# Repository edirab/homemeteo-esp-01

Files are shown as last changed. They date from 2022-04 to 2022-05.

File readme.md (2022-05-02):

## Проект домашней метеостанции на ESP-01 и Arduino

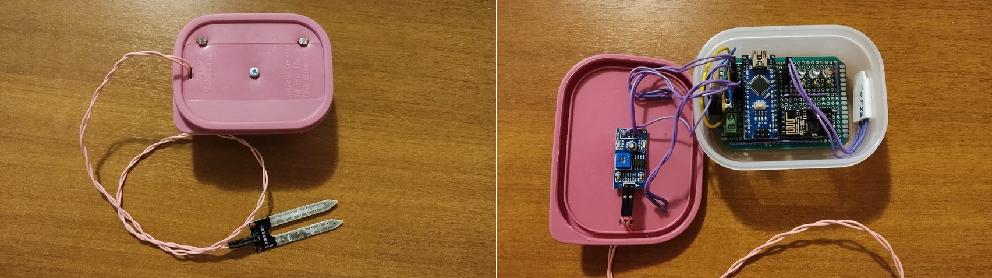
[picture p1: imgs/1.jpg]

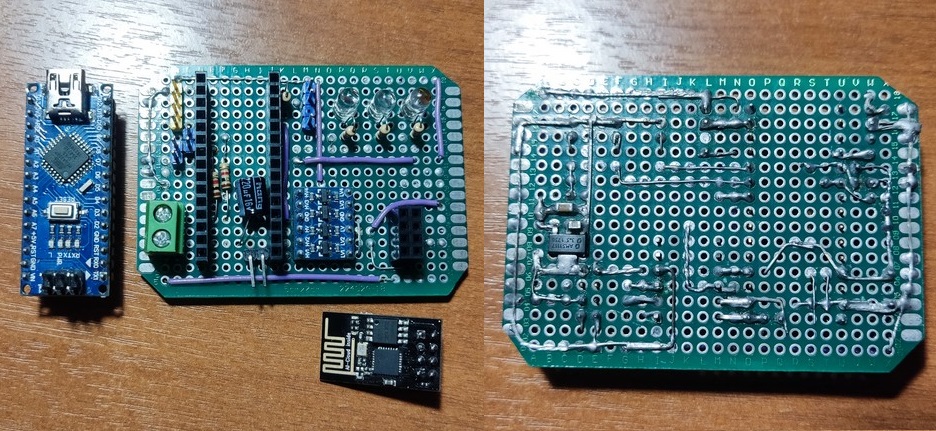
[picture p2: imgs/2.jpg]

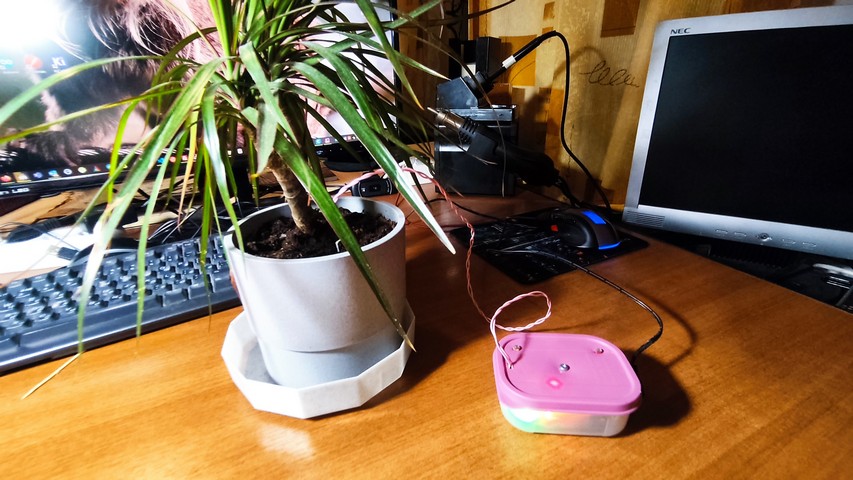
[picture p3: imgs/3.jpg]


### О проекте:

Устройство раз в 2 секунды собирает данные о 
- температуре, 
- влажности воздуха, 
- влажности почвы и 
- относительной освещённости в двух точках 

Пакет по локальной сети через wifi отправляется MQTT-брокеру `mosquitto`, развёрнутом на `Raspberry Pi 3B`. Скрипт `mqtt_test.py`, который обработывает callback от брокера, накапливает данные, добавляет к ним временную метку и раз в 10 минут производит запись в базу данных.

Раз в сутки производится резервное копирование БД на флешку.
За день накапливается ~1,7 Mb

Собранные данные можно проанализировать и определить, например, 
- частоту полива цветка
- изменения температуры и влажности воздуха с временами года,
- изменение освещённости в течение дня и в течение года
- оценить продолжительность светового дня
( в том числе и во сколько автор ложится спать :) )

### Цели проекта: 

- освоить микроконтроллер `ESP 8266` в его проестейшей версии `ESP 01`
- познакомиться с протоколом MQTT
- реализовать надёжную двунаправленную связь по UART между микроконтроллерами на основе протокола с подтверждением
- углубить познания в отладке `cron`

### Состав репозитория

- Скетч `meteo.ino` для Arduino
- Скетч `esp_test.ino` для ESP-01
- Python-скрипт `mqtt_test.py`
- `bash`-скрипт для резервного копирования
- Проект KiCad 6.0: 
    + схема электическая принципиальная
    + примерная компоновка печатной платы
    + Bill of materials
- фото устройства
- описание для настройки автозапуска

### Развёртывание ПО

1. Установить зависимости
```shell
sudo apt update && sudo apt upgrade
pip3 install pysqlite3
pip3 install paho-mqtt
pip3 install python-telegram-bot --upgrade
pip3 install matplotlib
sudo apt install -y mosquitto mosquitto-clients
sudo systemctl enable mosquitto.service
```
2. Настроить `mqtt`-брокер
- отредактировать системный конфигурационный файл или
```shell
sudo nano /etc/mosquitto/mosquitto.conf
> listener 1883
> allow_anonymous true
```
- скопировать конфигурацию `my.conf`: `sudo cp <path_to_repo/my.conf> /etc/mosquitto/conf.d/`

3. `sudo reboot`
4. Проверка конфигурации брокера:
```shell
	mosquitto_sub -d -t hello/world
	mosquitto_pub -d -t hello/world -m "Hello from Terminal window 2!"
	mosquitto_sub -t home/#
```

### Настройка автозапуска приложения и резервного копирования

1. Устанавливаем права и запускаем вручную, чтобы создать первоначальный файл базы данных на флешке.
```shell
chmod +x *.sh
./mqtt_backup.sh
```
2. Редактируем таблицу `cron` от имени обычного пользователя. Явно добавляем переменные окружения, т.к. у `cron` они отличаются
```shell
crontab -e

SHELL=/bin/bash
HOME=/home/pi
PATH=/usr/local/sbin:/usr/local/bin:/usr/sbin:/usr/bin:/sbin:/bin:/usr/local/games:/usr/games	

@reboot 	 /usr/bin/python3 /home/pi/Documents/mqtt_test.py >> /home/pi/Documents/1.log &
# Каждый день в 15:50
50 15 * * *  /bin/bash  /home/pi/Documents/mqtt_backup.sh
```

3. Считываем заново таблицу
```shell
sudo service cron reload
```
4. Проверка автозапуска
```shell
sudo reboot
ps -ax | grep mqtt
```

#### Важно при настройке автозапуска по cron

1. Пути ко всем ресурсам как в `crontab`, так и внутри скрипта, лучше прописывать абсолютные
2. Ресурсы, к которым обраются скрипты, должны иметь соотв. права (БД и файл логов доступны для чтения/записи)
3. Использовать лучше таблицу для обычного пользователя, а не `root`, в противном случае придётся устанавливать все библиотеки и для root: `sudo pip3 install pysqlite3`
4. ! Формат записи: `# m h  dom mon dow   command` - сначала минуты!
5. Про переносе файла с windows на linux могут слететь окончания строк: `dos2unix <file>`
6. Для отладки пользоваться гайдом [отсюда](https://stackoverflow.com/questions/22743548/cronjob-not-running)

### Процесс разработки

- [x] Устанока и настройка `mqtt`-брокера на Raspberry Pi
- [x] Поиск/проверка скрипта на python для записи данных, полученных от брокера
- [x] Разработка тестового ПО для ESP-01 для отладки приёма данных по MQTT. Например, посылка миллисекунд с момента включения
- [x] Определиться что будем использовать: ардуино в связке в esp 01

- [x] Для этого нужно определиться с составом датчиков. Берём
  + DHT 22 (влажность/температура)
  + Влажность почвы (аналоговый вход)
  + Пара фоторезисторов (аналоговые входы)
	
- [x] Разработать формат UART-посылки. Принят такой вариант:
	`27.2 35.6 3 456 645\r\n`

- [x] Разработать метод для разбора посылки на стороне esp 01, пришедшей по последовательному интерфейсу
- [x] Протестировать взаимодействие устройств на макетной плате -> Минимальное жизнеспособное приложение!
- [x] Добавить 3 светодиода на ардуино: 
  + красный для сигнализации о потере mqtt-соединения,
  + жёлтый - сухая почва цветка
  + зелёный для сигнализации о потере wifi-соединения,

- [x] Начертить схему электрическую принципиальную
- [x] Сделать компоновку печатной платы
- [x] Собрать устройство на паечной макетной плате

- [x] Необходимо разработать более надёжный протокол управления, основанный на сообщениях 
с уникальными префиксами и подтверждениями 

- [x] Доработать скрипт на python. Нельзя вести запись на карту памяти каждые 2 секунды.
	Слишком большой износ. Сделать раз в 3-5 минут
- [x] Изменить схему базы данных для более компактного хранения данных

- [ ] Добавить обработку ЖЁЛТОГО светодиода, подобрать пороговое значение для влажности почвы
- [ ] Оформить проект красиво: сделать фото устройства, составить Bill of Materials, сохранить в pdf схему эл. принц.

- [x] Разобраться как настроить автозапуск скрипта при старте Raspbian

- [x] Добавить `bash`-скрипт для резервного копирования БД на флешку раз в сутки по `cron`
- [ ] Сделать бота для Телеграм, чтобы можно было получить доступ к данным из любой точки мира с телефона. Продумать функционал

- [ ] Как насчёт добавить какой-либо пользовательский интерфейс для задания новых
  + логина/пароля для wifi-сети,
  + ip-адреса mqtt-брокера

### Заметки

- [Задать пароль и пользователя для брокера mosquitto](http://www.steves-internet-guide.com/mqtt-username-password-example/)

- Откуда взят [mqtt_test.py](https://lindevs.com/save-mqtt-data-to-sqlite-database-using-python/)

### Настройка VS Code для работы с Arduino

- Установить плагин Arduino
- Прописать путь к библиотекам, устанавливаемым через менеджер: 
	`corsair2\\Documents\\Arduino\\libraries` в `arduino.json`
- Добавить параметр `"output": "build"` в `arduino.json`

- Логин пароль `esp/esp`

### Bootloader debug messages

При загрузке esp выкидывает в uart отладочную информацию о работе загрузчика.
Поделать с этим ничего нельзя, только проигнорировать.
Скорость baudrate 74800 bit/s

Для отключения подобного вывода необходимо GPIO 15 (MTDO) [притянуть к нулю](https://www.esp32.com/viewtopic.php?t=10597) ,
но на ESP-01 вывод не разведён

```
	Posting for someone who still needs help on this topic.
	[Note: I'm using IDFv4.4 dev]

	Step1: got to menuconfig -> component config -> esp system settings -> channel for console output
	Set to - Custom UART
	Come one level behind and you'll find new options: UART peripheral to use for console output
	Set this to UART1
	You may also change the pins for UART0/1 that you are using now, by writing them in "UART Tx in GPIO# " option,
	if you want to use UART0 pins (Tx-GPIO1 & Rx-GPIO3) for other purposes or simply change their respective pins to somewhere more convenient while designing a complex PCB.

	Now, save and quit menuconfig -> flash operation is always done through UART0 (GPIO 1&3) but monitoring can now be done through UART1
	However, on every reset (POWER_ON/SW_RESET/WDT_RESET, etc.) the UART0 pins will output bootloader logs even-though they are supposed to be printed through UART1. For this, I tried setting BOOTLOADER and LOGOUTPUT to NONE in menuconfig, but it only stopped printing the respective logs on UART1 (coz. we had set it that way).

	The real solution is to pulldown GPIO15 so that even those bootup logs at UART0 can be stopped and now you're free to use the GPIO 1&3 for I/O operations.
```

Единственный вариант - пропустить эти сообщения

### Отладка автозапуска

Способы настройки автозапуска
- rc.local
- init.d
- systemd
- cron
- .bashrc

##### 1. Скрипт dbg_cron.py

1.1 Для отладки запуска в cron по reboot создадим простой скрипт.
Просто выводим дату и время в файл

В crontab обычного пользователя добавим 
	@reboot /usr/bin/python3 /home/pi/Documents/dbg_cron.py

- Просмотр изменений файла:
	watch -n 1 tail -1 /tmp/dbg_cron.log
	sudo tail -n20 -f /var/log/mosquitto/mosquitto.log
	sudo cp /home/pi/Documents/mymqttclient.service /etc/systemd/system/

=====

cat /var/log/syslog | grep cron
cat /var/log/syslog | grep CRON
tail -f /var/log/syslog

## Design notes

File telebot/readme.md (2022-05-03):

### Configuring bot

Список команд
start - запустить бота
help - вывести список команд
recent - получить последние данные
daily - статистика за сегодня

### Запуск бота в фоне и отвязка от консоли

```shell
	./bot.py &> /dev/null &
	disown <process-pid>
```

### TODO

- Выполнение команды /daily на RPI 3 занимает около 40 секунд, что слишком много.
Необходимо уменьшить выборку, скажем, до 300 точек

- Зафиксировать размер подмножества для одного графика. Скажем, 100 точек
- Сделать нормальные временные метки. Каждый час или каждые полчаса.
Зависит от диапазона измерений

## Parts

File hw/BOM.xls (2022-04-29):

Source: | D:\PycharmProjects\arduino\esp-mosquitto\hw\esm_mosquitto\esm_mosquitto.kicad_sch
Date: | 30.04.2022 0:29:25
Tool: | Eeschema (6.0.4)
Generator: | C:\Program Files\KiCad\6.0\bin\scripting\plugins/bom_csv_grouped_by_value_with_fp.py
Component Count: | 21
Ref | Qnty | Description
A1 | 1 | Arduino_Nano v3
C1 | 1 | Capacitor D5_P2.5 mm 220 u
C3 | 1 | Capacitor SMD 0805 10u
C4 | 1 | Capacitor SMD 0805 22u
D1 | 1 | LED D5 mm Green
D2 | 1 | LED D5 mm Yellow
D3 | 1 | LED D5 mm Red
J1 | 1 | Pin Header 2.54 mm 1x04 Vertical
J2 | 1 | Barrel_Jack P5 mm
R1, R3 | 2 | GL55 Photoresistor
R2, R4 | 2 | Resistor_L6.3mm_D2.5mm 1k
R5 | 1 | Resistor_L6.3mm_D2.5mm 10k
R8 - R10 | 3 | Resistor_L6.3mm_D2.5mm 470 Ohm
U1 | 1 | ESP-01 module
U2 | 1 | DHT 11 - Temperature and humidity module
U3 | 1 | Logic_Level_Converter BSS138
U5 | 1 | AMS1117-3.3 SOT-223 - 1A Low Dropout regulator

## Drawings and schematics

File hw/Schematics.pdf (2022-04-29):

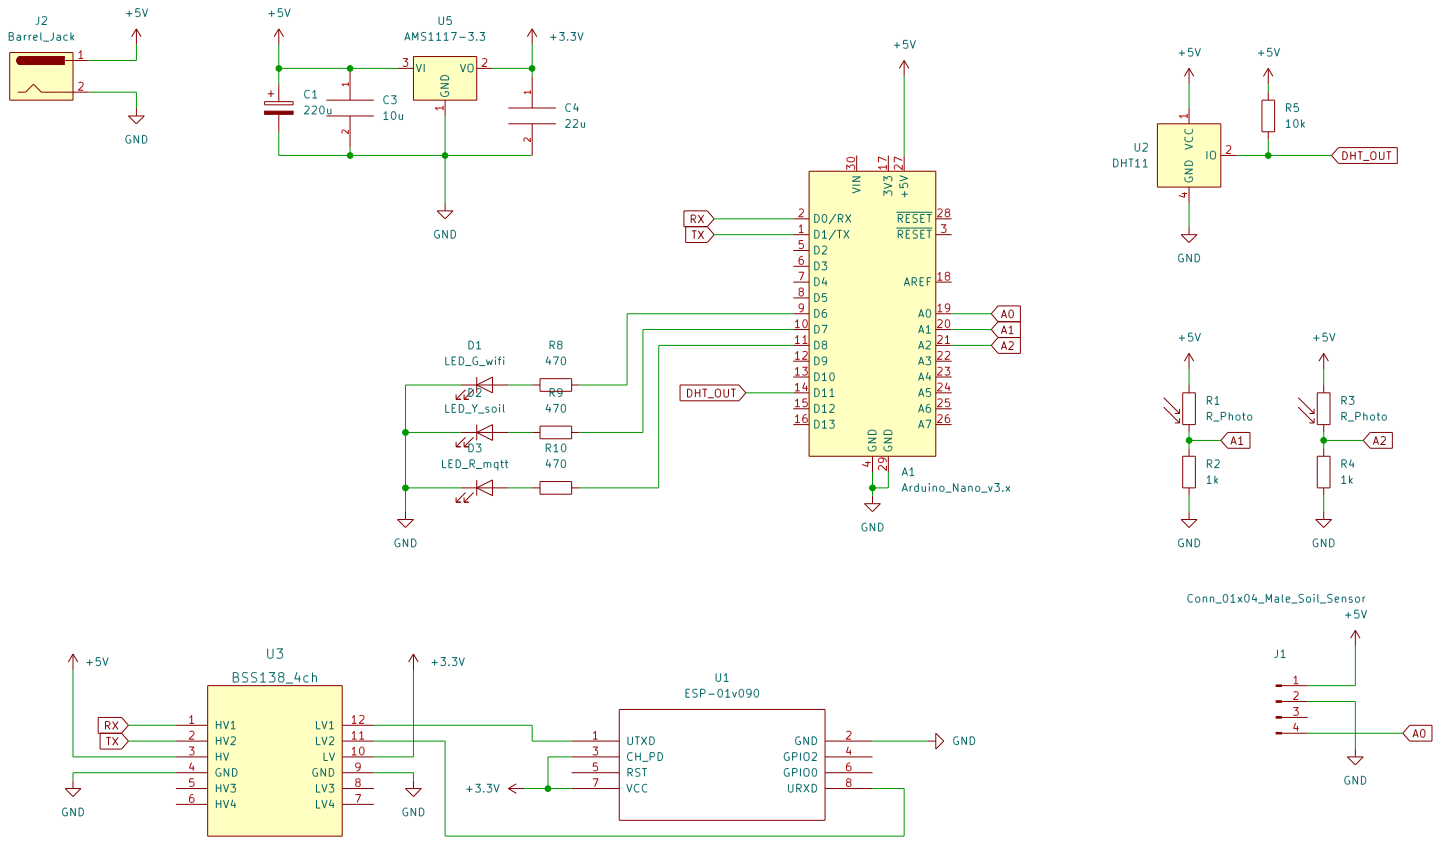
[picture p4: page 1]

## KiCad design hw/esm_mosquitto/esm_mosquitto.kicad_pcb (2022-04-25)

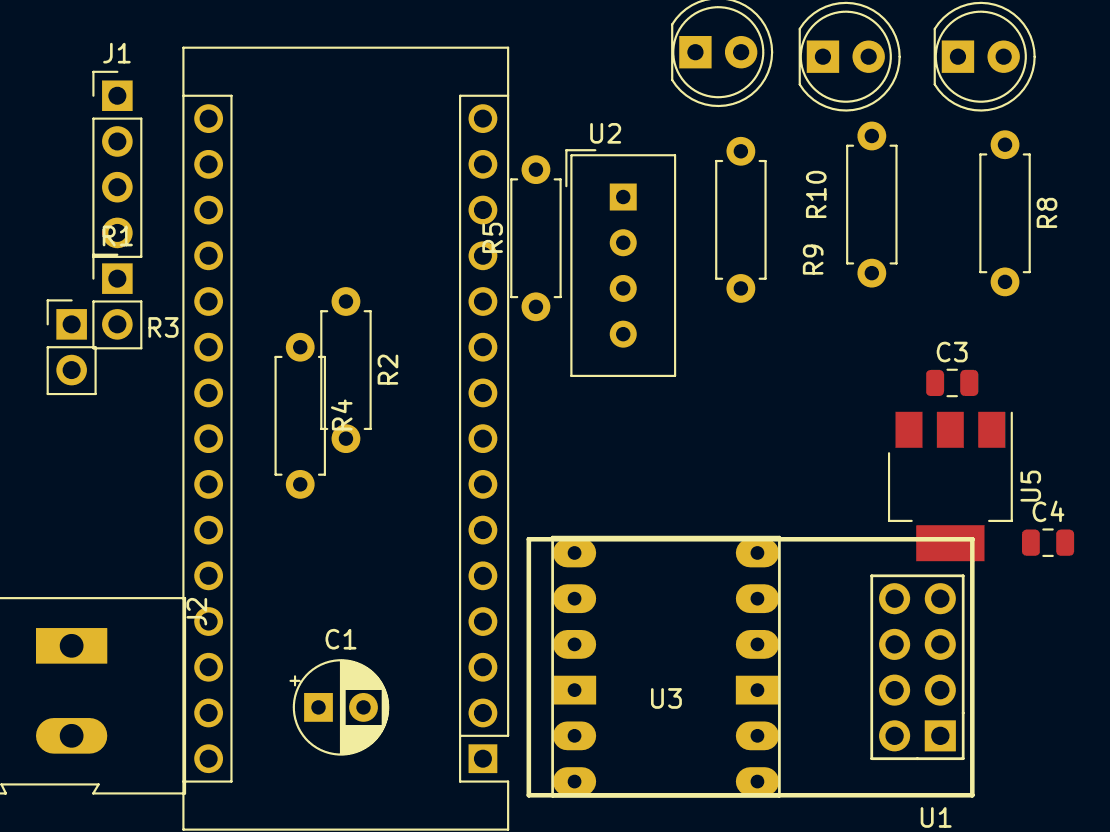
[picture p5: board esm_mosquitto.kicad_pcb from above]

Board: 2 copper layers, 21 parts (0 on the bottom side), 17 nets, no tracks yet.

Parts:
A1: Arduino_Nano_v3.x; Arduino_Nano
C1: 220u; CP_Radial_D5.0mm_P2.50mm
C3: 10u; C_0805_2012Metric
C4: 22u; C_0805_2012Metric
D1: LED_G_wifi; LED_D5.0mm_Clear
D2: LED_Y_soil; LED_D5.0mm_Clear
D3: LED_R_mqtt; LED_D5.0mm_Clear
J1: Conn_01x04_Male_Soil_Sensor; PinHeader_1x04_P2.54mm_Vertical
J2: Barrel_Jack; TerminalBlock_Altech_AK300-2_P5.00mm
R1, R3: R_Photo; PinHeader_1x02_P2.54mm_Vertical
R2, R4: 1k; R_Axial_DIN0207_L6.3mm_D2.5mm_P7.62mm_Horizontal
R5: 10k; R_Axial_DIN0207_L6.3mm_D2.5mm_P7.62mm_Horizontal
R8, R9, R10: 470; R_Axial_DIN0207_L6.3mm_D2.5mm_P7.62mm_Horizontal
U1: ESP-01v090; ESP-01
U2: DHT11; Aosong_DHT11_5.5x12.0_P2.54mm
U3: BSS138_4ch; BSS138
U5: AMS1117-3.3; SOT-223-3_TabPin2

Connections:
+3V3: C4.1, U1.3 (CH_PD), U1.7 (VCC), U3.10 (LV), U5.2 (VO)
+5V: A1.27 (+5V), C1.1, C3.1, J1.1, J2.1, R1.1, R3.1, R5.1, U2.1 (VCC), U3.3 (HV), U5.3 (VI)
A0: A1.19 (A0), J1.4
A1: A1.20 (A1), R1.2, R2.1
A2: A1.21 (A2), R3.2, R4.1
DHT_OUT: A1.14 (D11), R5.2, U2.2 (IO)
GND: A1.4 (GND), A1.29 (GND), C1.2, C3.2, C4.2, D1.1 (K), D2.1 (K), D3.1 (K), J1.2, J2.2, R2.2, R4.2, U1.2 (GND), U2.4 (GND), U3.4 (GND), U3.9 (GND), U5.1 (GND)
unnamed: A1.9 (D6), R8.2
unnamed: A1.10 (D7), R9.2
unnamed: A1.11 (D8), R10.2
unnamed: D1.2 (A), R8.1
unnamed: D2.2 (A), R9.1
unnamed: D3.2 (A), R10.1
unnamed: U1.1 (UTXD), U3.12 (LV1)
unnamed: U1.8 (URXD), U3.11 (LV2)
RX: A1.2 (D0/RX), U3.1 (HV1)
TX: A1.1 (D1/TX), U3.2 (HV2)

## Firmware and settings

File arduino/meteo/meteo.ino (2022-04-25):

#include <DHT_U.h>
#include <DHT.h>

 
#define DHTPIN  11     // what pin we're connected to
#define DHTTYPE DHT22   // DHT 22  (AM2302)

#define LED_MQTT 8 //  Red
#define LED_SOIL 7 // Yellow
#define LED_WIFI 6 // Green


#define DEBUG_PIN 5

// conn statuses
#define MSG_PREFIX "METEO_"
#define WIFI_FAIL 1
#define WIFI_OK	2
#define MQTT_FAIL 3
#define MQTT_OK 4


#define PERIOD 2000 // msec

struct luminance
{
    uint16_t r1;
    uint16_t r2;
};

struct meteo_data
{
    String temp, hum, soil;
    String lum1, lum2;
};

class MyMeteo
{
    public:
        explicit MyMeteo() : dht(DHTPIN, DHTTYPE) 
        {
            dht.begin();
        }

        void check_connection()
        {

            uint64_t timest = millis();
            uint64_t now_;

            do 
            {
                now_ = millis();
                
                if (Serial.available())
                {
                    String s1 = Serial.readStringUntil('\n');

                    if (s1.startsWith(MSG_PREFIX))
                    {
                        digitalWrite(DEBUG_PIN, HIGH);
                        /*
                            Сделано с целью избежать проблем с разными символами окончания строк \r\n vs \n
                            у ESP 01 и терминала VS Code
                        */
                        switch(s1.charAt(6) - '0')
                        {
                            case WIFI_FAIL:
                                digitalWrite(LED_WIFI, HIGH);
                                Serial.println("ACK_1");
                                break;
                            case WIFI_OK:
                                digitalWrite(LED_WIFI, LOW);
                                Serial.println("ACK_2");
                                break;
                            case MQTT_FAIL:
                                digitalWrite(LED_MQTT, HIGH);
                                Serial.println("ACK_3");
                                break;
                            case MQTT_OK:
                                digitalWrite(LED_MQTT, LOW);
                                Serial.println("ACK_4");
                                break;
                        }
                        //Serial.print(s1);
                        digitalWrite(DEBUG_PIN, LOW);
                    }
                }
            }
            while (now_ - timest < PERIOD );
            return;
        }

        void send_parsel()
        {
            get_DHT();
            get_soil();
            get_luminance();

            String parsel = data.temp + " " + data.hum + " " +
                data.soil + " " + data.lum1 + " " + data.lum2;
            
            Serial.println(parsel);
            return;
        }

    private:
        DHT dht;
        meteo_data data;

        /*
            1023 - разрыв цепи, абсолютно сухой грунт
            ~350-400 если окунуть в воду
        */
        void get_soil()
        {
            int a0 = analogRead(A0);

            if (a0 < 350)
                a0 = 350;
            
            // переворачиваем диапазон. 0 - сухая почва
            a0 = map(a0, 350, 1023, 100, 0);
            data.soil = String(a0);
            return;
        }

        /*
            0 - абсолютная темнота, 
            ~700-800 - направленная яркая лампа  
        */
        void get_luminance()
        {
            uint16_t lum_r1 = analogRead(A1);
            uint16_t lum_r2 = analogRead(A2);

            data.lum1 = String(lum_r1);
            data.lum2 = String(lum_r2);
            return;
        }

        void get_DHT()
        {
            float tempC = dht.readTemperature();
            float hum = dht.readHumidity();

            if (isnan(hum) )
            {
                //Serial.println("Failed to read humidity from DHT sensor!");
                data.hum = String("-99");
            }
            else
            {
                data.hum = String(hum);
            }

            if (isnan(tempC))
            {
                data.temp = String("-99");
            }
            else
            {
                data.temp = String(tempC);
            }
            return;
        }
}; // end MyMeteo




MyMeteo mymeteo;

void setup()
{
    pinMode(LED_WIFI, OUTPUT);
    pinMode(LED_MQTT, OUTPUT);
    pinMode(DEBUG_PIN, OUTPUT);

    digitalWrite(DEBUG_PIN, HIGH);
    // Для пропуска отладочного вывода загрузчика esp 01
    delay(20);
    Serial.begin(115200);
    digitalWrite(DEBUG_PIN, LOW);
    
}


void loop()
{
    mymeteo.send_parsel();
    mymeteo.check_connection();

    return;
}

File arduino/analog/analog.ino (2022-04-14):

struct luminance
{
    uint16_t r1;
    uint16_t r2;
};


void setup()
{
    Serial.begin(9600);
}

/*
    1023 - разрыв цепи, абсолютно сухой грунт
    ~350-400 если окунуть в воду
*/
int get_soil()
{
    int a0 = analogRead(A0);

    if (a0 < 350)
        a0 = 350;
    
    // переворачиваем диапазон. 0 - сухая почва
    a0 = map(a0, 350, 1023, 100, 0);
    return a0;
}


/*
    
*/
void get_luminance( luminance& lum )
{
    lum.r1 = analogRead(A1);
    lum.r2 = analogRead(A2);

    return;
}


void loop()
{
    
    luminance lum;

    Serial.print("Soil: ");
    Serial.println( get_soil() );

    Serial.print("Lum: ");
    get_luminance(lum);
    Serial.print(lum.r1);
    Serial.print(" ");
    Serial.println(lum.r2);

    delay(2000);
    return;
}

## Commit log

2022-04-14 Начало проекта ESP-метеостанция
2022-04-14 Тестовый пример для обработки аналоговых данных
2022-04-14 Дополнен пример для ESP-01: написан разбор строки с данными, принятой по UART
2022-04-15 Создано минимальное жизнеспособное приложение. Код для ардуино объединил в себе все части. Исправлен баг порядка отправки данных в ESP-01
    [analog.ino, meteo.ino]
2022-04-18 Начало разработки схемы электрической принципиальной и компоновки печатной платы Не удаётся состыковать в обратную сторону ESP 01 Arduino для передачи информации о статусе беспроводного соединения
    [esm_mosquitto.kicad_pcb, esm_mosquitto.kicad_sch]
2022-04-18 Решена проблема с различными окончаниями строк, но ардуино всё равно не всегда принимает сообщения. Необходимо упростить протокол. 1 символ вместо целой строки
2022-04-18 Решена проблема с отбрасыванием мусора (отладочные сообщения загрузчика) от esp-01 на старте. Протокол отправика стстуса соединения теперь из одного байта. Это нехорошо, нужно сообщение подлиннее, чт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
2022-04-19 Компоновка завершена
    [esm_mosquitto.kicad_pcb, esm_mosquitto.kicad_sch]
2022-04-21 Собрано устройство на паечной макетной плате. Исправлены ошибки при монтаже, проверены напряжения питания. Изменена схема формирования напряжения 3.3 В, переназначены выводы для светодиодов и датчика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
    [esm_mosquitto.kicad_pcb, esm_mosquitto.kicad_sch]
2022-04-22 - Исправлена ошибка в подключении ESP 01: вывод EN подтянут к питанию - Допаяны последние провода - Устройство собрано в корпус
    [esm_mosquitto.kicad_pcb, esm_mosquitto.kicad_sch]
2022-04-25 - Исправлено подключение фоторезисторов: фоторезистор и резистор 1к поменяны местами - Допаян длинный провод для вилки датчика влажности почвы - Устройство проверено, работает как ожидается
    [esm_mosquitto.kicad_pcb, esm_mosquitto.kicad_sch]
2022-04-25 - Модифицирован протокол передачи статуса соединения: добавлен уникальный префикс сообщения и циклическая отправка до момента получения подтверждения - Проверена работа передачи статусов 3 и 4 (отклю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
    [esm_mosquitto.kicad_sch]
2022-04-26 - В скрипте python запись в БД теперь происходит не раз в 2 секунды, а раз в 2 минуты. - Необходимо модифицировать схему БД, иначе слишком большой объём данных - Обнаружен баг в коде разбора строки н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
2022-04-26 - Изменена схема базы данных на более экономную - Соответственно, изменена логика периодической записи строк в БД в скрипте на python - Расширение теперь sqlite3
2022-04-26 - Начало написания ноутбука для анализа временных рядов - Исправлен баг с временной меткой
2022-04-26 - Настроен автозапуск python-скрипта по перезагрузке
2022-04-27 - Принято решение переработать формат посылки для mqtt-брокера, поскольку объединение данных из разных топиков вызывает сложности. Теперь все измерения пересылаются без изменений одной строкой. - Мод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
2022-04-27 - Переработан и значительно упрощён скрипт на python - Приложение в процессе тестирования
2022-04-28 - Настроен автозапуск по перезагрузке под cron
2022-04-28 - Настроен автозапуск резервного копирования
2022-04-28 - Реализован набор методов для анализа данных за произвольный период времени
2022-04-29 - Выборка данных каждые 10 секунд
2022-04-29 - Подготовлены изображения устройства
2022-04-29 - Добавлена схема электрическая принципиальная в pdf и Bill of materials
    [BOM.xls]
2022-04-30 - Начало создания телеграм-бота: минимальное жизнеспособное приложение - Readme: инструкция по установке зависимостей
2022-05-02 - Методы из jupyter ноутбука перенесены с файл stat.py. - Оформление графиков: размеры подписей и шрифтов - Написан метод для разбора параметров команды - Добавлен отладочный вывод в mqtt_test.py
2022-05-02 - Релизована команда /daily и её перегруженная версия /daily dd.mm - Обновлена база данных локально - Настроено сохранение изображений без обрезки подписей
2022-05-02 - Дописан обработчик команды help - Все команды зарегистрированы в BotFather и высплывают при нажатии на кнопку Меню - Пути к изображениям изменены на tmpfs
2022-05-03 - Настроен запуск бота на RPi - Исправлены пути в скрипте резервного копирования - Путь к БД перенесён в config.py - Построени графиков с помощью pandas в ноутбуке
